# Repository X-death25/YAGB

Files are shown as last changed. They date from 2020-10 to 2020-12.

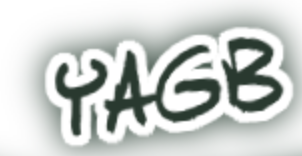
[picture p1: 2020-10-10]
PCB/gfx/yagb.PNG

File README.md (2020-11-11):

# YAGB
Yes Another GameBoy dumper  
STM32 USB Game Boy / Color cartridge Reader/Writer 

YAGB_pcb YAGB_pcb2  

What is it ?
-----

YAGB is an USB cart Reader/Flasher for Nintendo Gameboy / Gameboy Color. 
You can backup/restore your game ROMs/save games to your PC and write ROMs to third pary Flash cart.
it's a full usp high speed programmer and 100% open source Hardware & Sofyware.
You can backup / restore your cartridge and save for use it in Flashcart or Emu.
Feel free to do what you want with that 

Product Feature :
-----

    Read Nintendo Gameboy / Color cartridge up to 16 Meg
    Support Bankswitch for ROM & Saves
    Manage / Backup / Restore your own saves
    Reflash Third-Party Cartridges
    Universal Serial Bus USB2 Power & Use
    Multi OS compatibility Windows/Linux/Mac
    Open Source Hardware & Software
    
How to use it :
-----

You just need a micro USB to USB cable. Plug it and start the software.
Operating System Compatibility

Microsoft Windows XP / 7 / 8 / 10 / Linux / MAC OS

What make it special ?
-----

I wanted to use only classic component for the hardware easy findable on the net. Board microprocessor uses its own native USB transfer protocol so it's fast even for the large games, no need for any extra USB transceiver. I have made the choice to have fully open source hardware & software parts. All of the part list is easy to solder, even for a complete beginner, so everyone can make it. You can also buy a ready to use dumper.

Where i can buy it ?
-----

https://www.tindie.com/products/xdeath/yagb-yes-another-gameboy-dumper/

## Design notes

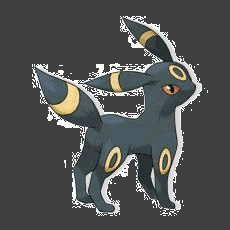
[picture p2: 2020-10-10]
PCB/gfx/noctali.png

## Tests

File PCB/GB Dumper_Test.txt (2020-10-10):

(kicad_pcb (version 20171130) (host pcbnew 5.0.2-bee76a0~70~ubuntu18.10.1)

  (general
    (thickness 1.2)
    (drawings 50)
    (tracks 478)
    (zones 0)
    (modules 24)
    (nets 40)
  )

  (page A4)
  (title_block
    (title GB-BRK-SLOT-A)
    (rev v1.0)
    (company https://gekkio.fi)
  )

  (layers
    (0 F.Cu signal)
    (31 B.Cu signal)
    (32 B.Adhes user)
    (33 F.Adhes user)
    (34 B.Paste user)
    (35 F.Paste user)
    (36 B.SilkS user)
    (37 F.SilkS user)
    (38 B.Mask user)
    (39 F.Mask user)
    (40 Dwgs.User user)
    (41 Cmts.User user)
    (42 Eco1.User user)
    (43 Eco2.User user)
    (44 Edge.Cuts user)
    (45 Margin user)
    (46 B.CrtYd user)
    (47 F.CrtYd user)
    (48 B.Fab user)
    (49 F.Fab user)
  )

  (setup
    (last_trace_width 0.32)
    (user_trace_width 0.8)
    (trace_clearance 0.2)
    (zone_clearance 0.254)
    (zone_45_only yes)
    (trace_min 0.2)
    (segment_width 0.2)
    (edge_width 0.15)
    (via_size 0.6)
    (via_drill 0.4)
    (via_min_size 0.4)
    (via_min_drill 0.3)
    (user_via 1 0.8)
    (uvia_size 0.3)
    (uvia_drill 0.1)
    (uvias_allowed no)
    (uvia_min_size 0.2)
    (uvia_min_drill 0.1)
    (pcb_text_width 0.3)
    (pcb_text_size 1.5 1.5)
    (mod_edge_width 0.15)
    (mod_text_size 1 1)
    (mod_text_width 0.15)
    (pad_size 1.524 1.524)
    (pad_drill 0.762)
    (pad_to_mask_clearance 0)
    (solder_mask_min_width 0.2)
    (aux_axis_origin 0 0)
    (visible_elements FFFFFF7F)
    (pcbplotparams
      (layerselection 0x010fc_ffffffff)
      (usegerberextensions false)
      (usegerberattributes false)
      (usegerberadvancedattributes false)
      (creategerberjobfile true)
      (excludeedgelayer false)
      (linewidth 0.100000)
      (plotframeref false)
      (viasonmask false)
      (mode 1)
      (useauxorigin false)
      (hpglpennumber 1)
      (hpglpenspeed 20)
      (hpglpendiameter 15.000000)
      (psnegative false)
      (psa4output false)
      (plotreference true)
      (plotvalue true)
      (plotinvisibletext false)
      (padsonsilk false)
      (subtractmaskfromsilk false)
      (outputformat 1)
      (mirror false)
      (drillshape 0)
      (scaleselection 1)
      (outputdirectory "gerber/"))
  )

  (net 0 "")
  (net 1 "Net-(D1-Pad2)")
  (net 2 +5V)
  (net 3 GND)
  (net 4 /A0)
  (net 5 /PHI)
  (net 6 /A1)
  (net 7 /~WR)
  (net 8 /A2)
  (net 9 /~RD)
  (net 10 /A3)
  (net 11 /~CS)
  (net 12 /A4)
  (net 13 /D0)
  (net 14 /A5)
  (net 15 /D1)
  (net 16 /A6)
  (net 17 /D2)
  (net 18 /A7)
  (net 19 /D3)
  (net 20 /A8)
  (net 21 /D4)
  (net 22 /A9)
  (net 23 /D5)
  (net 24 /A10)
  (net 25 /D6)
  (net 26 /A11)
  (net 27 /D7)
  (net 28 /A12)
  (net 29 /~RES)
  (net 30 /A13)
  (net 31 /VIN)
  (net 32 /A14)
  (net 33 /A15)
  (net 34 "Net-(D2-Pad2)")
  (net 35 "Net-(D3-Pad2)")
  (net 36 "Net-(D4-Pad2)")
  (net 37 "Net-(D5-Pad2)")
  (net 38 "Net-(D6-Pad2)")
  (net 39 "Net-(J3-Pad1)")

  (net_class Default "This is the default net class."
    (clearance 0.2)
    (trace_width 0.32)
    (via_dia 0.6)
    (via_drill 0.4)
    (uvia_dia 0.3)
    (uvia_drill 0.1)
    (add_net /A0)
    (add_net /A1)
    (add_net /A10)
    (add_net /A11)
    (add_net /A12)
    (add_net /A13)
    (add_net /A14)
    (add_net /A15)
    (add_net /A2)
    (add_net /A3)
    (add_net /A4)
    (add_net /A5)
    (add_net /A6)
    (add_net /A7)
    (add_net /A8)
    (add_net /A9)
    (add_net /D0)
    (add_net /D1)
    (add_net /D2)
    (add_net /D3)
    (add_net /D4)
    (add_net /D5)
    (add_net /D6)
    (add_net /D7)
    (add_net /PHI)
    (add_net /VIN)
    (add_net /~CS)
    (add_net /~RD)
    (add_net /~RES)
    (add_net /~WR)
    (add_net "Net-(D1-Pad2)")
    (add_net "Net-(D2-Pad2)")
    (add_net "Net-(D3-Pad2)")
    (add_net "Net-(D4-Pad2)")
    (add_net "Net-(D5-Pad2)")
    (add_net "Net-(D6-Pad2)")
    (add_net "Net-(J3-Pad1)")
  )

  (net_class Power ""
    (clearance 0.3)
    (trace_width 0.8)
    (via_dia 1)
    (via_drill 0.8)
    (uvia_dia 0.3)
    (uvia_drill 0.1)
    (add_net +5V)
    (add_net GND)
  )

  (module Connector_PinHeader_2.54mm:PinHeader_1x02_P2.54mm_Vertical (layer F.Cu) (tedit 59FED5CC) (tstamp 5C2EC759)
    (at 58.3 103.3 180)
    (descr "Through hole straight pin header, 1x02, 2.54mm pitch, single row")
    (tags "Through hole pin header THT 1x02 2.54mm single row")
    (path /5C2E6B56)
    (fp_text reference JP1 (at 0 -2.33 180) (layer F.SilkS)
      (effects (font (size 1 1) (thickness 0.15)))
    )
    (fp_text value Jumper_NC_Small (at 0 4.87 180) (layer F.Fab)
      (effects (font (size 1 1) (thickness 0.15)))
    )
    (fp_text user %R (at 0 1.27 270) (layer F.Fab)
      (effects (font (size 1 1) (thickness 0.15)))
    )
    (fp_line (start 1.8 -1.8) (end -1.8 -1.8) (layer F.CrtYd) (width 0.05))
    (fp_line (start 1.8 4.35) (end 1.8 -1.8) (layer F.CrtYd) (width 0.05))
    (fp_line (start -1.8 4.35) (end 1.8 4.35) (layer F.CrtYd) (width 0.05))
    (fp_line (start -1.8 -1.8) (end -1.8 4.35) (layer F.CrtYd) (width 0.05))
    (fp_line (start -1.33 -1.33) (end 0 -1.33) (layer F.SilkS) (width 0.12))
    (fp_line (start -1.33 0) (end -1.33 -1.33) (layer F.SilkS) (width 0.12))
    (fp_line (start -1.33 1.27) (end 1.33 1.27) (layer F.SilkS) (width 0.12))
    (fp_line (start 1.33 1.27) (end 1.33 3.87) (layer F.SilkS) (width 0.12))
    (fp_line (start -1.33 1.27) (end -1.33 3.87) (layer F.SilkS) (width 0.12))
    (fp_line (start -1.33 3.87) (end 1.33 3.87) (layer F.SilkS) (width 0.12))
    (fp_line (start -1.27 -0.635) (end -0.635 -1.27) (layer F.Fab) (width 0.1))
    (fp_line (start -1.27 3.81) (end -1.27 -0.635) (layer F.Fab) (width 0.1))
    (fp_line (start 1.27 3.81) (end -1.27 3.81) (layer F.Fab) (width 0.1))
    (fp_line (start 1.27 -1.27) (end 1.27 3.81) (layer F.Fab) (width 0.1))
    (fp_line (start -0.635 -1.27) (end 1.27 -1.27) (layer F.Fab) (width 0.1))
    (pad 2 thru_hole oval (at 0 2.54 180) (size 1.7 1.7) (drill 1) (layers *.Cu *.Mask)
      (net 39 "Net-(J3-Pad1)"))
    (pad 1 thru_hole rect (at 0 0 180) (size 1.7 1.7) (drill 1) (layers *.Cu *.Mask)
      (net 2 +5V))
    (model ${KISYS3DMOD}/Connector_PinHeader_2.54mm.3dshapes/PinHeader_1x02_P2.54mm_Vertical.wrl
      (at (xyz 0 0 0))
      (scale (xyz 1 1 1))
      (rotate (xyz 0 0 0))
    )
  )

  (module Resistor_SMD:R_1206_3216Metric_Pad1.42x1.75mm_HandSolder (layer F.Cu) (tedit 5B301BBD) (tstamp 5BF060DE)
    (at 64.25 101.69 270)
    (descr "Resistor SMD 1206 (3216 Metric), square (rectangular) end terminal, IPC_7351 nominal with elongated pad for handsoldering. (Body size source: http://www.tortai-tech.com/upload/download/2011102023233369053.pdf), generated with kicad-footprint-generator")
    (tags "resistor handsolder")
    (path /5BF0DED2)
    (attr smd)
    (fp_text reference R7 (at -0.01 2.24) (layer F.SilkS)
      (effects (font (size 1 1) (thickness 0.15)))
    )
    (fp_text value 0R (at 1.34 2.3) (layer F.Fab)
      (effects (font (size 1 1) (thickness 0.15)))
    )
    (fp_text user %R (at 0 0 270) (layer F.Fab)
      (effects (font (size 0.8 0.8) (thickness 0.12)))
    )
    (fp_line (start 2.45 1.12) (end -2.45 1.12) (layer F.CrtYd) (width 0.05))
    (fp_line (start 2.45 -1.12) (end 2.45 1.12) (layer F.CrtYd) (width 0.05))
    (fp_line (start -2.45 -1.12) (end 2.45 -1.12) (layer F.CrtYd) (width 0.05))
    (fp_line (start -2.45 1.12) (end -2.45 -1.12) (layer F.CrtYd) (width 0.05))
    (fp_line (start -0.602064 0.91) (end 0.602064 0.91) (layer F.SilkS) (width 0.12))
    (fp_line (start -0.602064 -0.91) (end 0.602064 -0.91) (layer F.SilkS) (width 0.12))
    (fp_line (start 1.6 0.8) (end -1.6 0.8) (layer F.Fab) (width 0.1))
    (fp_line (start 1.6 -0.8) (end 1.6 0.8) (layer F.Fab) (width 0.1))
    (fp_line (start -1.6 -0.8) (end 1.6 -0.8) (layer F.Fab) (width 0.1))
    (fp_line (start -1.6 0.8) (end -1.6 -0.8) (layer F.Fab) (width 0.1))
    (pad 2 smd roundrect (at 1.4875 0 270) (size 1.425 1.75) (layers F.Cu F.Paste F.Mask) (roundrect_rratio 0.175439)
      (net 2 +5V))
    (pad 1 smd roundrect (at -1.4875 0 270) (size 1.425 1.75) (layers F.Cu F.Paste F.Mask) (roundrect_rratio 0.175439)
      (net 39 "Net-(J3-Pad1)"))
    (model ${KISYS3DMOD}/Resistor_SMD.3dshapes/R_1206_3216Metric.wrl
      (at (xyz 0 0 0))
      (scale (xyz 1 1 1))
      (rotate (xyz 0 0 0))
    )
  )

  (module LED_SMD:LED_0603_1608Metric (layer F.Cu) (tedit 5B301BBE) (tstamp 5A985B06)
    (at 65 148.4)
    (descr "LED SMD 0603 (1608 Metric), square (rectangular) end terminal, IPC_7351 nominal, (Body size source: http://www.tortai-tech.com/upload/download/2011102023233369053.pdf), generated with kicad-footprint-generator")
    (tags diode)
    (path /5A985CB3)
    (attr smd)
    (fp_text reference D1 (at -15.5 0.3) (layer F.SilkS)
      (effects (font (size 1 1) (thickness 0.15)))
    )
    (fp_text value LED (at 0 1.65) (layer F.Fab)
      (effects (font (size 1 1) (thickness 0.15)))
    )
    (fp_text user %R (at 0 0) (layer F.Fab)
      (effects (font (size 0.4 0.4) (thickness 0.06)))
    )
    (fp_line (start 1.48 0.73) (end -1.48 0.73) (layer F.CrtYd) (width 0.05))
    (fp_line (start 1.48 -0.73) (end 1.48 0.73) (layer F.CrtYd) (width 0.05))
    (fp_line (start -1.48 -0.73) (end 1.48 -0.73) (layer F.CrtYd) (width 0.05))
    (fp_line (start -1.48 0.73) (end -1.48 -0.73) (layer F.CrtYd) (width 0.05))
    (fp_line (start -1.485 0.735) (end 0.8 0.735) (layer F.SilkS) (width 0.12))
    (fp_line (start -1.485 -0.735) (end -1.485 0.735) (layer F.SilkS) (width 0.12))
    (fp_line (start 0.8 -0.735) (end -1.485 -0.735) (layer F.SilkS) (width 0.12))
    (fp_line (start 0.8 0.4) (end 0.8 -0.4) (layer F.Fab) (width 0.1))
    (fp_line (start -0.8 0.4) (end 0.8 0.4) (layer F.Fab) (width 0.1))
    (fp_line (start -0.8 -0.1) (end -0.8 0.4) (layer F.Fab) (width 0.1))
    (fp_line (start -0.5 -0.4) (end -0.8 -0.1) (layer F.Fab) (width 0.1))
    (fp_line (start 0.8 -0.4) (end -0.5 -0.4) (layer F.Fab) (width 0.1))
    (pad 2 smd roundrect (at 0.7875 0) (size 0.875 0.95) (layers F.Cu F.Paste F.Mask) (roundrect_rratio 0.25)
      (net 1 "Net-(D1-Pad2)"))
    (pad 1 smd roundrect (at -0.7875 0) (size 0.875 0.95) (layers F.Cu F.Paste F.Mask) (roundrect_rratio 0.25)
      (net 3 GND))
    (model ${KISYS3DMOD}/LED_SMD.3dshapes/LED_0603_1608Metric.wrl
      (at (xyz 0 0 0))
      (scale (xyz 1 1 1))
      (rotate (xyz 0 0 0))
    )
  )

  (module Connector_PinHeader_2.54mm:PinHeader_2x16_P2.54mm_Vertical locked (layer F.Cu) (tedit 59FED5CC) (tstamp 5A985B2A)
    (at 68.45 120 90)
    (descr "Through hole straight pin header, 2x16, 2.54mm pitch, double rows")
    (tags "Through hole pin header THT 2x16 2.54mm double row")
    (path /5A985BF6)
    (fp_text reference J2 (at 1.27 -2.33 90) (layer F.SilkS)
      (effects (font (size 1 1) (thickness 0.15)))
    )
    (fp_text value Conn_02x16_Odd_Even (at 1.27 40.43 90) (layer F.Fab)
      (effects (font (size 1 1) (thickness 0.15)))
    )
    (fp_text user %R (at 1.27 19.05 180) (layer F.Fab)
      (effects (font (size 1 1) (thickness 0.15)))
    )
    (fp_line (start 4.35 -1.8) (end -1.8 -1.8) (layer F.CrtYd) (width 0.05))
    (fp_line (start 4.35 39.9) (end 4.35 -1.8) (layer F.CrtYd) (width 0.05))
    (fp_line (start -1.8 39.9) (end 4.35 39.9) (layer F.CrtYd) (width 0.05))
    (fp_line (start -1.8 -1.8) (end -1.8 39.9) (layer F.CrtYd) (width 0.05))
    (fp_line (start -1.33 -1.33) (end 0 -1.33) (layer F.SilkS) (width 0.12))
    (fp_line (start -1.33 0) (end -1.33 -1.33) (layer F.SilkS) (width 0.12))
    (fp_line (start 1.27 -1.33) (end 3.87 -1.33) (layer F.SilkS) (width 0.12))
    (fp_line (start 1.27 1.27) (end 1.27 -1.33) (layer F.SilkS) (width 0.12))
    (fp_line (start -1.33 1.27) (end 1.27 1.27) (layer F.SilkS) (width 0.12))
    (fp_line (start 3.87 -1.33) (end 3.87 39.43) (layer F.SilkS) (width 0.12))
    (fp_line (start -1.33 1.27) (end -1.33 39.43) (layer F.SilkS) (width 0.12))
    (fp_line (start -1.33 39.43) (end 3.87 39.43) (layer F.SilkS) (width 0.12))
    (fp_line (start -1.27 0) (end 0 -1.27) (layer F.Fab) (width 0.1))
    (fp_line (start -1.27 39.37) (end -1.27 0) (layer F.Fab) (width 0.1))
    (fp_line (start 3.81 39.37) (end -1.27 39.37) (layer F.Fab) (width 0.1))
    (fp_line (start 3.81 -1.27) (end 3.81 39.37) (layer F.Fab) (width 0.1))
    (fp_line (start 0 -1.27) (end 3.81 -1.27) (layer F.Fab) (width 0.1))
    (pad 32 thru_hole oval (at 2.54 38.1 90) (size 1.7 1.7) (drill 1) (layers *.Cu *.Mask)
      (net 3 GND))
    (pad 31 thru_hole oval (at 0 38.1 90) (size 1.7 1.7) (drill 1) (layers *.Cu *.Mask)
      (net 33 /A15))
    (pad 30 thru_hole oval (at 2.54 35.56 90) (size 1.7 1.7) (drill 1) (layers *.Cu *.Mask)
      (net 31 /VIN))
    (pad 29 thru_hole oval (at 0 35.56 90) (size 1.7 1.7) (drill 1) (layers *.Cu *.Mask)
      (net 32 /A14))
    (pad 28 thru_hole oval (at 2.54 33.02 90) (size 1.7 1.7) (drill 1) (layers *.Cu *.Mask)
      (net 29 /~RES))
    (pad 27 thru_hole oval (at 0 33.02 90) (size 1.7 1.7) (drill 1) (layers *.Cu *.Mask)
      (net 30 /A13))
    (pad 26 thru_hole oval (at 2.54 30.48 90) (size 1.7 1.7) (drill 1) (layers *.Cu *.Mask)
      (net 27 /D7))
    (pad 25 thru_hole oval (at 0 30.48 90) (size 1.7 1.7) (drill 1) (layers *.Cu *.Mask)
      (net 28 /A12))
    (pad 24 thru_hole oval (at 2.54 27.94 90) (size 1.7 1.7) (drill 1) (layers *.Cu *.Mask)
      (net 25 /D6))
    (pad 23 thru_hole oval (at 0 27.94 90) (size 1.7 1.7) (drill 1) (layers *.Cu *.Mask)
      (net 26 /A11))
    (pad 22 thru_hole oval (at 2.54 25.4 90) (size 1.7 1.7) (drill 1) (layers *.Cu *.Mask)
      (net 23 /D5))
    (pad 21 thru_hole oval (at 0 25.4 90) (size 1.7 1.7) (drill 1) (layers *.Cu *.Mask)
      (net 24 /A10))
    (pad 20 thru_hole oval (at 2.54 22.86 90) (size 1.7 1.7) (drill 1) (layers *.Cu *.Mask)
      (net 21 /D4))
    (pad 19 thru_hole oval (at 0 22.86 90) (size 1.7 1.7) (drill 1) (layers *.Cu *.Mask)
      (net 22 /A9))
    (pad 18 thru_hole oval (at 2.54 20.32 90) (size 1.7 1.7) (drill 1) (layers *.Cu *.Mask)
      (net 19 /D3))
    (pad 17 thru_hole oval (at 0 20.32 90) (size 1.7 1.7) (drill 1) (layers *.Cu *.Mask)
      (net 20 /A8))
    (pad 16 thru_hole oval (at 2.54 17.78 90) (size 1.7 1.7) (drill 1) (layers *.Cu *.Mask)
      (net 17 /D2))
    (pad 15 thru_hole oval (at 0 17.78 90) (size 1.7 1.7) (drill 1) (layers *.Cu *.Mask)
      (net 18 /A7))
    (pad 14 thru_hole oval (at 2.54 15.24 90) (size 1.7 1.7) (drill 1) (layers *.Cu *.Mask)
      (net 15 /D1))
    (pad 13 thru_hole oval (at 0 15.24 90) (size 1.7 1.7) (drill 1) (layers *.Cu *.Mask)
      (net 16 /A6))
    (pad 12 thru_hole oval (at 2.54 12.7 90) (size 1.7 1.7) (drill 1) (layers *.Cu *.Mask)
      (net 13 /D0))
    (pad 11 thru_hole oval (at 0 12.7 90) (size 1.7 1.7) (drill 1) (layers *.Cu *.Mask)
      (net 14 /A5))
    (pad 10 thru_hole oval (at 2.54 10.16 90) (size 1.7 1.7) (drill 1) (layers *.Cu *.Mask)
      (net 11 /~CS))
    (pad 9 thru_hole oval (at 0 10.16 90) (size 1.7 1.7) (drill 1) (layers *.Cu *.Mask)
      (net 12 /A4))
    (pad 8 thru_hole oval (at 2.54 7.62 90) (size 1.7 1.7) (drill 1) (layers *.Cu *.Mask)
      (net 9 /~RD))
    (pad 7 thru_hole oval (at 0 7.62 90) (size 1.7 1.7) (drill 1) (layers *.Cu *.Mask)
      (net 10 /A3))
    (pad 6 thru_hole oval (at 2.54 5.08 90) (size 1.7 1.7) (drill 1) (layers *.Cu *.Mask)
      (net 7 /~WR))
    (pad 5 thru_hole oval (at 0 5.08 90) (size 1.7 1.7) (drill 1) (layers *.Cu *.Mask)
      (net 8 /A2))
    (pad 4 thru_hole oval (at 2.54 2.54 90) (size 1.7 1.7) (drill 1) (layers *.Cu *.Mask)
      (net 5 /PHI))
    (pad 3 thru_hole oval (at 0 2.54 90) (size 1.7 1.7) (drill 1) (layers *.Cu *.Mask)
      (net 6 /A1))
    (pad 2 thru_hole oval (at 2.54 0 90) (size 1.7 1.7) (drill 1) (layers *.Cu *.Mask)
      (net 2 +5V))
    (pad 1 thru_hole rect (at 0 0 90) (size 1.7 1.7) (drill 1) (layers *.Cu *.Mask)
      (net 4 /A0))
    (model ${KISYS3DMOD}/Connector_PinHeader_2.54mm.3dshapes/PinHeader_2x16_P2.54mm_Vertical.wrl
      (at (xyz 0 0 0))
      (scale (xyz 1 1 1))
      (rotate (xyz 0 0 0))
    )
  )

  (module Resistor_SMD:R_0603_1608Metric (layer F.Cu) (tedit 5B301BBD) (tstamp 5A985B90)
    (at 65 146.8)
    (descr "Resistor SMD 0603 (1608 Metric), square (rectangular) end terminal, IPC_7351 nominal, (Body size source: http://www.tortai-tech.com/upload/download/2011102023233369053.pdf), generated with kicad-footprint-generator")
    (tags resistor)
    (path /5A985D2A)
    (attr smd)
    (fp_text reference R1 (at -15.5 0.6) (layer F.SilkS)
      (effects (font (size 1 1) (thickness 0.15)))
    )
    (fp_text value 3.3k (at 0 1.65) (layer F.Fab)
      (effects (font (size 1 1) (thickness 0.15)))
    )
    (fp_text user %R (at 0 0) (layer F.Fab)
      (effects (font (size 0.4 0.4) (thickness 0.06)))
    )
    (fp_line (start 1.48 0.73) (end -1.48 0.73) (layer F.CrtYd) (width 0.05))
    (fp_line (start 1.48 -0.73) (end 1.48 0.73) (layer F.CrtYd) (width 0.05))
    (fp_line (start -1.48 -0.73) (end 1.48 -0.73) (layer F.CrtYd) (width 0.05))
    (fp_line (start -1.48 0.73) (end -1.48 -0.73) (layer F.CrtYd) (width 0.05))
    (fp_line (start -0.162779 0.51) (end 0.162779 0.51) (layer F.SilkS) (width 0.12))
    (fp_line (start -0.162779 -0.51) (end 0.162779 -0.51) (layer F.SilkS) (width 0.12))
    (fp_line (start 0.8 0.4) (end -0.8 0.4) (layer F.Fab) (width 0.1))
    (fp_line (start 0.8 -0.4) (end 0.8 0.4) (layer F.Fab) (width 0.1))
    (fp_line (start -0.8 -0.4) (end 0.8 -0.4) (layer F.Fab) (width 0.1))
    (fp_line (start -0.8 0.4) (end -0.8 -0.4) (layer F.Fab) (width 0.1))
    (pad 2 smd roundrect (at 0.7875 0) (size 0.875 0.95) (layers F.Cu F.Paste F.Mask) (roundrect_rratio 0.25)
      (net 1 "Net-(D1-Pad2)"))
    (pad 1 smd roundrect (at -0.7875 0) (size 0.875 0.95) (layers F.Cu F.Paste F.Mask) (roundrect_rratio 0.25)
      (net 2 +5V))
    (model ${KISYS3DMOD}/Resistor_SMD.3dshapes/R_0603_1608Metric.wrl
      (at (xyz 0 0 0))
      (scale (xyz 1 1 1))
      (rotate (xyz 0 0 0))
    )
  )

  (module Capacitor_SMD:C_1206_3216Metric (layer F.Cu) (tedit 5B301BBE) (tstamp 5A986974)
    (at 67 132.6 180)
    (descr "Capacitor SMD 1206 (3216 Metric), square (rectangular) end terminal, IPC_7351 nominal, (Body size source: http://www.tortai-tech.com/upload/download/2011102023233369053.pdf), generated with kicad-footprint-generator")
    (tags capacitor)
    (path /5A985D9A)
    (attr smd)
    (fp_text reference C1 (at 0 1.9 180) (layer F.SilkS)
      (effects (font (size 1 1) (thickness 0.15)))
    )
    (fp_text value 10uF (at 5.3 0 180) (layer F.Fab)
      (effects (font (size 1 1) (thickness 0.15)))
    )
    (fp_text user %R (at 0 0 180) (layer F.Fab)
      (effects (font (size 0.8 0.8) (thickness 0.12)))
    )
    (fp_line (start 2.28 1.12) (end -2.28 1.12) (layer F.CrtYd) (width 0.05))
    (fp_line (start 2.28 -1.12) (end 2.28 1.12) (layer F.CrtYd) (width 0.05))
    (fp_line (start -2.28 -1.12) (end 2.28 -1.12) (layer F.CrtYd) (width 0.05))
    (fp_line (start -2.28 1.12) (end -2.28 -1.12) (layer F.CrtYd) (width 0.05))
    (fp_line (start -0.602064 0.91) (end 0.602064 0.91) (layer F.SilkS) (width 0.12))
    (fp_line (start -0.602064 -0.91) (end 0.602064 -0.91) (layer F.SilkS) (width 0.12))
    (fp_line (start 1.6 0.8) (end -1.6 0.8) (layer F.Fab) (width 0.1))
    (fp_line (start 1.6 -0.8) (end 1.6 0.8) (layer F.Fab) (width 0.1))
    (fp_line (start -1.6 -0.8) (end 1.6 -0.8) (layer F.Fab) (width 0.1))
    (fp_line (start -1.6 0.8) (end -1.6 -0.8) (layer F.Fab) (width 0.1))
    (pad 2 smd roundrect (at 1.4 0 180) (size 1.25 1.75) (layers F.Cu F.Paste F.Mask) (roundrect_rratio 0.2)
      (net 3 GND))
    (pad 1 smd roundrect (at -1.4 0 180) (size 1.25 1.75) (layers F.Cu F.Paste F.Mask) (roundrect_rratio 0.2)
      (net 2 +5V))
    (model ${KISYS3DMOD}/Capacitor_SMD.3dshapes/C_1206_3216Metric.wrl
      (at (xyz 0 0 0))
      (scale (xyz 1 1 1))
      (rotate (xyz 0 0 0))
    )
  )

  (module Capacitor_SMD:C_0603_1608Metric (layer F.Cu) (tedit 5B301BBE) (tstamp 5A986979)
    (at 67.6 129.1 180)
    (descr "Capacitor SMD 0603 (1608 Metric), square (rectangular) end terminal, IPC_7351 nominal, (Body size source: http://www.tortai-tech.com/upload/download/2011102023233369053.pdf), generated with kicad-footprint-generator")
    (tags capacitor)
    (path /5A985DFF)
    (attr smd)
    (fp_text reference C2 (at 0.7 1.6 180) (layer F.SilkS)
      (effects (font (size 1 1) (thickness 0.15)))
    )
    (fp_text value 0.1uF (at 5.1 0 180) (layer F.Fab)
      (effects (font (size 1 1) (thickness 0.15)))
    )
    (fp_text user %R (at 0 0 180) (layer F.Fab)
      (effects (font (size 0.4 0.4) (thickness 0.06)))
    )
    (fp_line (start 1.48 0.73) (end -1.48 0.73) (layer F.CrtYd) (width 0.05))
    (fp_line (start 1.48 -0.73) (end 1.48 0.73) (layer F.CrtYd) (width 0.05))
    (fp_line (start -1.48 -0.73) (end 1.48 -0.73) (layer F.CrtYd) (width 0.05))
    (fp_line (start -1.48 0.73) (end -1.48 -0.73) (layer F.CrtYd) (width 0.05))
    (fp_line (start -0.162779 0.51) (end 0.162779 0.51) (layer F.SilkS) (width 0.12))
    (fp_line (start -0.162779 -0.51) (end 0.162779 -0.51) (layer F.SilkS) (width 0.12))
    (fp_line (start 0.8 0.4) (end -0.8 0.4) (layer F.Fab) (width 0.1))
    (fp_line (start 0.8 -0.4) (end 0.8 0.4) (layer F.Fab) (width 0.1))
    (fp_line (start -0.8 -0.4) (end 0.8 -0.4) (layer F.Fab) (width 0.1))
    (fp_line (start -0.8 0.4) (end -0.8 -0.4) (layer F.Fab) (width 0.1))
    (pad 2 smd roundrect (at 0.7875 0 180) (size 0.875 0.95) (layers F.Cu F.Paste F.Mask) (roundrect_rratio 0.25)
      (net 3 GND))
    (pad 1 smd roundrect (at -0.7875 0 180) (size 0.875 0.95) (layers F.Cu F.Paste F.Mask) (roundrect_rratio 0.25)
      (net 2 +5V))
    (model ${KISYS3DMOD}/Capacitor_SMD.3dshapes/C_0603_1608Metric.wrl
      (at (xyz 0 0 0))
      (scale (xyz 1 1 1))
      (rotate (xyz 0 0 0))
    )
  )
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

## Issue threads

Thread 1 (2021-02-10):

Component list

dennisjanssen, 2021-02-10:
Hi!

First of all, great project! I've been looking for an easy DIY method of making one of these. From what I can tell it's still WIP, but your goal is to be able to flash a new ROM to an unlocked flash cart?

I've been looking at the PCB files, from what I can tell I'll need these components:

- 2x 74LS273 (https://nl.aliexpress.com/item/1005001792133844.html?spm=a2g0o.cart.0.0.50d13c00pjkaV7&mp=1)
- 1x game cartridge slot (https://nl.aliexpress.com/item/4001322498055.html?spm=a2g0o.cart.0.0.50d13c00pjkaV7&mp=1)
- 2x MKS02 (https://nl.aliexpress.com/item/4000403102318.html)
- 1x STM32 board (https://nl.aliexpress.com/item/1005001621944261.html)

And then just order the PCB from PCBway, JLCPCB, ...

If I got all of that right I'll start ordering and build one.

X-death25, 2021-02-10:
Hi,
Yes sorry i missed the part list  👍
so :

74LS273N : https://fr.aliexpress.com/item/32879353216.html
GB/GBC cartridge slot : https://fr.aliexpress.com/item/33007365661.html
100nF condensator ( can works without but it's better ) :  https://fr.aliexpress.com/item/1005002060914434.html
STM32 ( i recommand the Rebotdyn design for better USB support but blue pill can works too :
https://fr.aliexpress.com/item/3301602535

And then yes just drag the gerber files on any PCB builder shop.
Wish you great build !

dennisjanssen, 2021-02-10:
This is great, thanks! Any idea on cartridge compatibility? I'm guessing it takes some custom work based on the cartridge chipset, since most flasher list these. Any recommendations?

dennisjanssen, 2021-04-08:
Just in case any other total noob like myself reads this afterwards, a USB TTL adapter apparently is also pretty useful when you order an STM32 that doesn't come preflashed.

I ordered this one: https://nl.aliexpress.com/item/4000308135007.html?spm=a2g0s.9042311.0.0.7b984c4dJZShqL

X-death25, 2021-04-10:
Hi,
you can also use ST-link clone and official STM32 ST-link utility

https://fr.aliexpress.com/item/1827010981.html?
After that i use this bootloader for dev
https://github.com/rogerclarkmelbourne/STM32duino-bootloader
and this for release ( user don't need to install driver for the second)
https://github.com/Serasidis/STM32_HID_Bootloader

dennisjanssen, 2021-04-15:
You are probably right, not having much luck with the USB-TTL adapter in any method available. Ordered an ST-LINK programmer on AliExpress now, so I'll be waiting for a while now.

I do have some cartridges around, as well as a bunch of Chinese reproductions, so very curious about compatibility. I noticed you added flash capabilities too, would be very interesting to flash ROMs to those Chinese cartridges. I'll keep you posted on progress!

dennisjanssen, 2021-04-18:
I managed to get it working with a UART adapter after all, got the HID bootloader on there and managed to flash your firmware through the script, so I'm fully done hardware wise!

Started testing with some cartridges, managed to dump one (type C9 according to the dumper), but you're right, Pokemon Red (MBC5) is giving me trouble. Also tried to dump a bootleg cartridge, which gave me a .gb file with the correct size, but it's not functional. Also tried to flash one of those with another ROM, no luck. What did work on that bootleg cartridge was erasing flash, it now says it's empty and will only return an empty .gb file when dumping. Weirdly enough the cartridge still works fine in a GameBoy, the ROM is still there.

dennisjanssen, 2021-04-19:
Sorry to spam these comments, but I've been combing through code and looking up other examples to add compatibility with more types of cartridges, when I came across this: https://github.com/lesserkuma/FlashGBX

They seems set up in a way that allows them to add more hardware devices to their flashing/dumping software and already offer a very broad range of different cartridges. Maybe it's a good idea to collaborate? Connect their software with your firmware to offer a very complete solution?

X-death25, 2021-04-20:
1)Good to read you have sucessfully flashed it , now with bootloader inside , update will be easier.
Did you have troubles with a lot of cartrige ? i have my all collections sucessfully.
Some games with MBC5 dumps correctly for exemple Oracle of Seasons.
Lots of chinese cartridge bootleg use crappy flash with no level shifter or some uncommun mapper clone.
Can you report me game that's don't works correctly ?
I don't have Rewritable GB cartridge in my hand so can't do real hardware test for reflash code.

2)Github links you show it's just a graphical interface for GBxCart and not include mapper support ( these code are in  GBxCart  firmware and maybe not open source).
GBxCart use Atmel 5V processor for better compatibility but harder to solder and costs a lot more.
All of these design is open source so feel free to do what you want with it.

dennisjanssen, 2021-04-20:
So far Pokemon Red gave me trouble, Power Rangers The Movie worked fine. But I'll test a bit more to rule out I have hardware trouble or something.

On the software side, bear with me. And quick disclaimer, I barely consider myself a programmer, so I might have all of this wrong. I took a look at GBxCart since they seem to have the broadest support for all kinds of cartridges. Turns out their firmware isn't exactly closed source, I found it here: https://github.com/insidegadgets/GBxCart-RW/blob/06b1ac4196e76209cee02668608f618dbebd87ed/MCU_Files/GBxCart_RW_v1.3_R22/main.c

I was expecting to see mappings for different kinds of cartridges as well, in that file. I haven't found much in there, but maybe I'm looking in the wrong places. As far as I can tell they handle this a bit more backwards than YAGB, where the software part handles the logic and mapping and the firmware just does the reading and writing parts. But you're way better placed to estimate that I suppose.

Anyway, next I started looking into how they communicate between software and firmware, to figure out how that works. FlashGBX seemed like a good place to start since they had to figure out the same thing. As far as I can tell the makers of FlashGBX didn't intend to only work with GBxCart, they even separated the hardware integration in a separate file (https://github.com/lesserkuma/FlashGBX/blob/master/FlashGBX/hw_GBxCartRW.py) that is loaded into an array of devices (https://github.com/lesserkuma/FlashGBX/blob/master/FlashGBX/FlashGBX_GUI.py#L11). That hardware file also seems to hand off certain functions to the firmware (like GBA_FLASH_WRITE_BYTE), which are named the same in the GBxCart fimware. In their commits I found indications that they added support for different kinds of cartridges, which struck me as weird because I also expected that part to be handled by the GBxCart firmware. Turns out they have a massive pile of config files for different types of cartridges (https://github.com/lesserkuma/FlashGBX/tree/master/FlashGBX/config), I'm guessing that's the mapping you mentioned?

Again, I might look at this all wrong (sorry if that's the case), but I think both FlashGBX and the GBxCart firmware have a lot of parts that might be useful for you to add more compatibility (or even troubleshoot the MBC5 cartridges). But it might even be interesting to update the firmware and work on a hardware file with the FlashGBX guys in order to piggyback on a lot of work they already did?

X-death25, 2021-05-09:
Hi,
i have made a special exe for MBC5 issues.
Could you test these file with your Pokemon Red ?
https://github.com/X-death25/YAGB/blob/main/Software/GB_Dumper_mbc5.exe

Greetings

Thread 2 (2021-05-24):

Write Save files

adri6412, 2021-05-24:
I have compiled your software to work on a rasperry pi but when i use the menu to write a dumped save file back to the cartdridge it hangs after i input the name in the save file dialog.

In my windows pc is working fine. Only linux is giving me problems

Is maybe the issue derived to something of the arm platform or is it a bug on linux?

adri6412, 2021-05-24:
I have not mentioned that all the other options do work (like dumping the rom and the save file) just the erase sram and the write sram functions are broken

Closed 2022-05-17.

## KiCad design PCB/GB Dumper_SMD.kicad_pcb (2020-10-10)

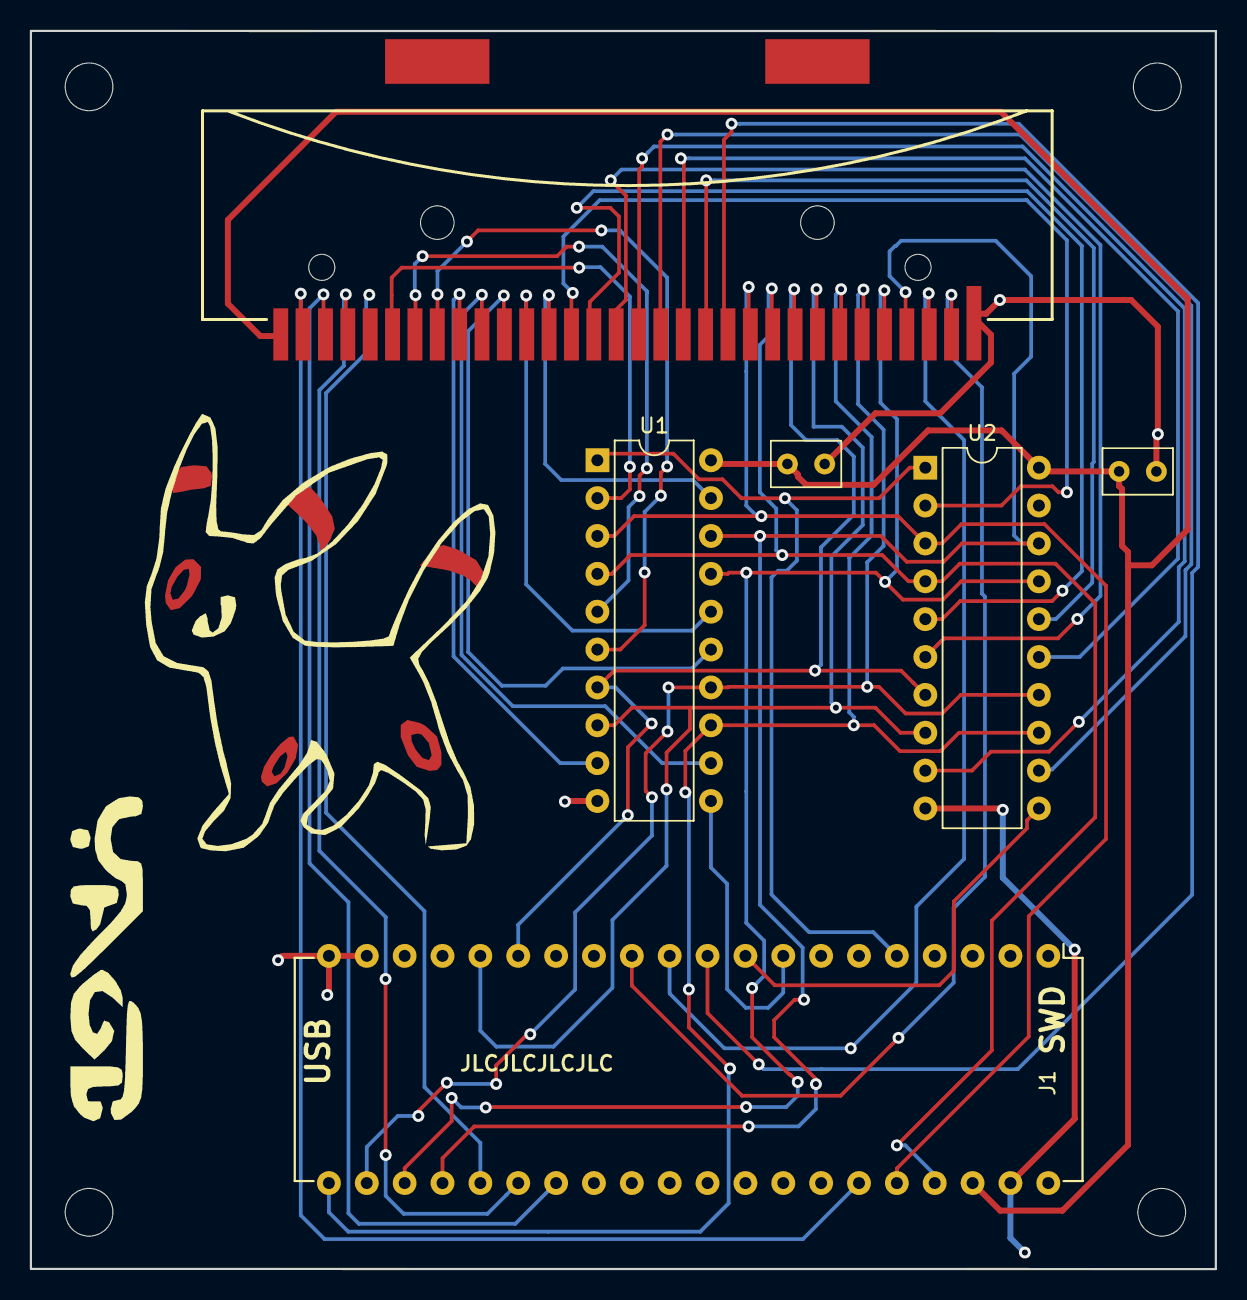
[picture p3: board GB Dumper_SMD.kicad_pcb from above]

Board: 2 copper layers, 79.5 x 83.1 mm, 4 parts (0 on the bottom side), 34 nets.

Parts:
J1: Conn_02x20_Counter_Clockwise; DIP-40_W15.24mm
J2: Conn_01x32_Male; GB_CART_4holes
U1, U2: 74LS273; DIP-20_W7.62mm

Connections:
A0: J2.6, U1.2
A1: J2.7, U1.5
A2: J2.8, U1.6
A3: J2.9, U1.9
A4: J2.10, U1.12
A5: J2.11, U1.15
A6: J2.12, U1.16
A7: J2.13, U1.19
A8: J2.14, U2.2
A9: J2.15, U2.5
A10: J2.16, U2.6
A11: J2.17, U2.9
A12: J2.18, U2.12
A13: J2.19, U2.15
A14: J2.20, U2.16
A15: J1.10, J2.21
Audio_IN: J1.12, J2.31
CPU_Clk: J1.37, J2.2
Clear: J1.5, U1.1, U2.1
Clk1: J1.8, U1.11
Clk2: J1.9, U2.11
D0: J1.36, J2.22, U1.3, U2.3
D1: J1.37, J2.23, U1.4, U2.4
D2: J1.15, J2.24, U1.7, U2.7
D3: J1.16, J2.25, U1.8, U2.8
D4: J1.21, J2.26, U1.13, U2.13
D5: J1.22, J2.27, U1.14, U2.14
D6: J1.23, J2.28, U1.17, U2.17
D7: J1.24, J2.29, U1.18, U2.18
GND: J1.19, J1.20, J1.39, J2.32, U1.10, U2.10
VCC5: J1.38, J2.1, U1.20, U2.20
~RD: J1.26, J2.4
~RST: J1.11, J2.30
~WE: J1.27, J2.3

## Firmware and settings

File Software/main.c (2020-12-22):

/*
 * \file main.c
 * \brief Libusb software for communicate with STM32
 * \author X-death for Ultimate-Consoles forum (http://www.ultimate-consoles.fr)
 * \date 2018/06
 *
 * just a simple sample for testing libusb and new code of Sega Dumper
 *
 * --------------------------------------------
 */

#include <stdio.h>
#include <stdlib.h>
#include <stdarg.h>
#include <string.h>
#include <ctype.h>
#include <time.h>
#include <math.h>

#include <libusb.h>
#include <assert.h>

// Specific Win32 lib ( only used for debug )

//#include <conio.h>

// USB Special Command

#define WAKEUP  0x10  // WakeUP for first STM32 Communication
#define READ_GB 0x11
#define READ_GB_SAVE 0x12
#define ERASE_GB_SAVE 0x17
#define WRITE_GB_SAVE 0x13
#define WRITE_GB_FLASH 	0x14
#define ERASE_GB_FLASH 0x15
#define ERASE_SECTOR 0x16
#define INFOS_ID 0x18
#define DEBUG_MODE 0x19

// Version 

#define MAX_VERSION 	1
#define MIN_VERSION 	2


// Sega Dumper Specific Function

void pause(char const *message)
{
    int c;
 
    printf("%s", message);
    fflush(stdout);
 
    while ((c = getchar()) != '\n' && c != EOF)
    {
    }
}


int main()
{

  // LibUSB Specific Var
    
  int res                      = 0;        /* return codes from libusb functions */
  libusb_device_handle* handle = 0;        /* handle for USB device */
  int kernelDriverDetached     = 0;        /* Set to 1 if kernel driver detached */
  int numBytes                 = 0;        /* Actual bytes transferred. */
  unsigned char usb_buffer_in[64] = {0};   /* 64 byte transfer buffer IN */
  unsigned char usb_buffer_out[64] = {0};  /* 64 byte transfer buffer OUT */
  unsigned long len            = 0;        /* Number of bytes transferred. */

   // Dumper Specific Var

    unsigned long i=0;
	unsigned long j=0;
    unsigned long k=0;
	int choixMenu=0;
	unsigned long address=0;
	unsigned char *BufferROM;
	unsigned char *BufferTemp;
	unsigned char *BufferRAM;
	unsigned char *buffer_save = NULL;
	char dump_name[64];
	int game_size=0;
	unsigned long save_size=0;
	FILE *myfile;
	const char * wheel[] = { "-","\\","|","/"}; //erase wheel
	unsigned char manufacturer_id=0;
	unsigned char chip_id=0;
	unsigned short flash_id=0;
	unsigned short sector_number=0;

  // Rom Header info

	unsigned char ROM_Logo[48];
    unsigned char Game_Name[16];
	unsigned char Rom_Type=0;
    unsigned long Rom_Size=0;
	unsigned long Ram_Size=0;
	unsigned char CGB=0;
	unsigned char SGB=0;

const unsigned char GB_Logo[48] = {
	0xCE, 0xED, 0x66, 0x66, 0xCC, 0x0D, 0x00, 0x0B, 0x03, 0x73, 0x00, 0x83, 0x00, 0x0C, 0x00, 0x0D, 
	0x00, 0x08, 0x11, 0x1F, 0x88, 0x89, 0x00, 0x0E, 0xDC, 0xCC, 0x6E, 0xE6, 0xDD, 0xDD, 0xD9, 0x99, 
	0xBB, 0xBB, 0x67, 0x63, 0x6E, 0x0E, 0xEC, 0xCC, 0xDD, 0xDC, 0x99, 0x9F, 0xBB, 0xB9, 0x33, 0x3E, 
};
   

   // Main Program   

    printf("\n");
    printf(" ---------------------------------\n");
    printf("    GB Dumper USB2 Software     \n");
    printf(" ---------------------------------\n");
	printf("\n");

    printf("Init LibUSB... \n");

  /* Initialise libusb. */

  res = libusb_init(0);
  if (res != 0)
  {
    fprintf(stderr, "Error initialising libusb.\n");
    return 1;
  }

    printf("LibUSB Init Sucessfully ! \n");


 printf("Detecting GameBoy Dumper... \n");

  /* Get the first device with the matching Vendor ID and Product ID. If
   * intending to allow multiple demo boards to be connected at once, you
   * will need to use libusb_get_device_list() instead. Refer to the libusb
   * documentation for details. */

  handle = libusb_open_device_with_vid_pid(0, 0x1209, 0xBEBA);

  if (!handle)
  {
    fprintf(stderr, "Unable to open device.\n");
    return 1;
  }

  /* Claim interface #0. */

 res = libusb_claim_interface(handle, 0);
  if (res != 0)
  {
	res = libusb_claim_interface(handle, 1);
	 if (res != 0)
  {
    printf("Error claiming interface.\n");
    return 1;}
  }

// Clean Buffer
  for (i = 0; i < 64; i++)
    {
      usb_buffer_in[i]=0x00;
      usb_buffer_out[i]=0x00;
	}


 printf("GameBoy Dumper Found ! \n");
 printf("Reading cartridge...\n");


 // At this step we can try to read the buffer wake up GB Dumper

  usb_buffer_out[0] = WAKEUP;// Affect request to  WakeUP Command

  libusb_bulk_transfer(handle, 0x01,usb_buffer_out, sizeof(usb_buffer_out), &numBytes, 0); // Send Packets to Sega Dumper
  
libusb_bulk_transfer(handle, 0x82, usb_buffer_in, sizeof(usb_buffer_in), &numBytes, 0); // Receive packets from Sega Dumper

		
    printf("\nGB Dumper %.*s",6, (char *)usb_buffer_in);
	printf("\n");
    printf("Hardware Firmware version : %d", usb_buffer_in[20]);
    printf(".%d\n", usb_buffer_in[21]);
    printf("Software Firmware version : %d",MAX_VERSION);
    printf(".%d\n",MIN_VERSION);


  for (i = 0; i < 64; i++)
    {
      usb_buffer_in[i]=0x00;
      usb_buffer_out[i]=0x00;
	}

// Now try to detect cartridge type : GB or GBA or Empty

printf("\nTry to read cartridge type ...\n");

address=260;
game_size=260+64;
usb_buffer_out[0] = READ_GB;
usb_buffer_out[1] = address & 0xFF ;
usb_buffer_out[2] = (address & 0xFF00)>>8;
usb_buffer_out[3]=(address & 0xFF0000)>>16;
usb_buffer_out[5]=game_size & 0xFF;
usb_buffer_out[6]=(game_size & 0xFF00)>>8;
usb_buffer_out[7]=(game_size & 0xFF0000)>>16;
usb_buffer_out[4] = 0; // Slow Mode
libusb_bulk_transfer(handle, 0x01,usb_buffer_out, sizeof(usb_buffer_out), &numBytes, 60000);
libusb_bulk_transfer(handle, 0x82,usb_buffer_in,64, &numBytes, 60000);

for (i = 0; i < 48; i++)
    {
        ROM_Logo [i] = usb_buffer_in[i];
		
    }

if(memcmp((unsigned char *)ROM_Logo,(unsigned char *)GB_Logo,48) == 0)
	{
		printf("Nintendo GameBoy cartridge detected !");
	}
else {printf("Bad header , cartridge dirty or empty Flash ROM");}


/*
printf("\nDisplaying USB IN buffer\n\n");

   for (i = 0; i < 64; i++)
    {
        printf("%02X ",usb_buffer_in[i]);
		j++;
		if (j==16){printf("\n");j=0;}
    }
*/

// Now try to read ROM GB Header


address=308;
game_size=308+64;
usb_buffer_out[0] = READ_GB;
usb_buffer_out[1] = address & 0xFF ;
usb_buffer_out[2] = (address & 0xFF00)>>8;
usb_buffer_out[3]=(address & 0xFF0000)>>16;
usb_buffer_out[5]=game_size & 0xFF;
usb_buffer_out[6]=(game_size & 0xFF00)>>8;
usb_buffer_out[7]=(game_size & 0xFF0000)>>16;
usb_buffer_out[4] = 0; // Slow Mode
libusb_bulk_transfer(handle, 0x01,usb_buffer_out, sizeof(usb_buffer_out), &numBytes, 60000);
libusb_bulk_transfer(handle, 0x82,usb_buffer_in,64, &numBytes, 60000);

/*
printf("\nDisplaying USB IN buffer\n\n");

   for (i = 0; i < 64; i++)
    {
        printf("%02X ",usb_buffer_in[i]);
		j++;
		if (j==16){printf("\n");j=0;}
    }
*/
printf("\nReading ROM Header...\n");
printf("\nGame Title : ");
for (i=0; i<16; i++) {Game_Name[i]=usb_buffer_in[i];} // ROM Name
printf("%.*s",16,(char *) Game_Name);
Rom_Type = usb_buffer_in[19];
printf("\nCartridge Type : %02X ",Rom_Type);
if ( Rom_Type == 0x00){ printf("(ROM ONLY)");}
if ( Rom_Type == 0x01){ printf("(MBC1)");}
if ( Rom_Type == 0x02){ printf("(MBC1+RAM)");}
if ( Rom_Type == 0x03){ printf("(MBC1+RAM+BATTERY)");}
if ( Rom_Type == 0x05){ printf("(MBC2)");}
if ( Rom_Type == 0x06){ printf("(MBC2+BATTERY)");}
if ( Rom_Type == 0x08){ printf("(ROM+RAM)");}
if ( Rom_Type == 0x09){ printf("(ROM+RAM+BATTERY)");}
if ( Rom_Type == 0x0B){ printf("(MMM01)");}
if ( Rom_Type == 0x0C){ printf("(MMM01+RAM)");}
if ( Rom_Type == 0x0D){ printf("(MMM01+RAM+BATTERY)");}
if ( Rom_Type == 0x0F){ printf("(MBC3+TIMER+BATTERY)");}
if ( Rom_Type == 0x10){ printf("(MBC3+TIMER+RAM+BATTERY)");}
if ( Rom_Type == 0x11){ printf("(MBC3)");}
if ( Rom_Type == 0x12){ printf("(MBC3+RAM)");}
if ( Rom_Type == 0x13){ printf("(MBC3+RAM+BATTERY)");}
if ( Rom_Type == 0x19){ printf("(MBC5)");}
if ( Rom_Type == 0x1A){ printf("(MBC5+RAM)");}
if ( Rom_Type == 0x1B){ printf("(MBC5+RAM+BATTERY)");}
if ( Rom_Type == 0x1C){ printf("(MBC5+RUMBLE)");}
if ( Rom_Type == 0x1D){ printf("(MBC5+RUMBLE+RAM)");}
if ( Rom_Type == 0x1E){ printf("(MBC5+RUMBLE+RAM+BATTERY)");}
if ( Rom_Type == 0x20){ printf("(MBC6)");}
if ( Rom_Type == 0x22){ printf("(MBC7+SENSOR+RUMBLE+RAM+BATTERY)");}
if ( Rom_Type == 0xFC){ printf("(POCKET CAMERA)");}
if ( Rom_Type == 0xFD){ printf("(BANDAI TAMA5)");}
if ( Rom_Type == 0xFE){ printf("(HuC3)");}
if ( Rom_Type == 0xFF){ printf("(HuC1+RAM+BATTERY)");}
Rom_Size= (32768 << usb_buffer_in[20]); // Rom Size
printf("\nGame Size is :  %ld Ko",Rom_Size/1024);
if ( Rom_Type != 0x06) {
Ram_Size = usb_buffer_in[21];
printf("\nRam Size : ");
if ( Ram_Size == 0x00){ printf("None");}
if ( Ram_Size == 0x01){ printf("2 Ko");save_size=2*1024;}
if ( Ram_Size == 0x02){ printf("8 Ko");save_size=8*1024;}
if ( Ram_Size == 0x03){ printf("32 Ko ");save_size=32*1024;}
if ( Ram_Size == 0x04){ printf("128 Ko");save_size=128*1024;}
if ( Ram_Size == 0x05){ printf("64 Ko");save_size=64*1024;}
}
else{Ram_Size = 512; printf("\nRam Size : 512 bytes ");save_size=512;}
CGB = usb_buffer_in[15];
if ( CGB  == 0xC0){ printf("\nGame only works on GameBoy Color");}
else { printf("\nGameBoy / GameBoy Color compatible game");}
SGB = usb_buffer_in[18];
if ( SGB  == 0x00){ printf("\nNo Super GameBoy enhancements");}
if ( SGB  == 0x03){ printf("\nGame have Super GameBoy enhancements");}

// MBC5 custom inits


// Clean Buffer
  for (i = 0; i < 64; i++)
    {
      usb_buffer_in[i]=0x00;
      usb_buffer_out[i]=0x00;
	}
/*
if (Rom_Type == 0x19 || 0x1A || 0x1B || 0x1C || 0x1D || 0x1E)
{printf("\nMBC5 detected please wait until init is completed ...\n");
address=0;
game_size = Rom_Size;
usb_buffer_out[0] = READ_GB;           				
usb_buffer_out[1]=address & 0xFF;
usb_buffer_out[2]=(address & 0xFF00)>>8;
usb_buffer_out[3]=(address & 0xFF0000)>>16;
usb_buffer_out[4]=0;
usb_buffer_out[5]=game_size & 0xFF;
usb_buffer_out[6]=(game_size & 0xFF00)>>8;
usb_buffer_out[7]=(game_size & 0xFF0000)>>16;
usb_buffer_out[8]=Rom_Type;
BufferTemp = (unsigned char*)malloc(game_size); 
     for (i=0; i<game_size; i++)
        {
            BufferTemp[i]=0x00;
        }			


						libusb_bulk_transfer(handle, 0x01,usb_buffer_out, sizeof(usb_buffer_out), &numBytes, 60000);
						res = libusb_bulk_transfer(handle, 0x82,BufferTemp,game_size*2 , &numBytes, 60000);
  							if (res != 0)
  								{
    								printf("Error \n");
    								return 1;
  								}     
 						printf("MBC5 init completed sucessfully !\n");}
*/

// Clean Buffer
  for (i = 0; i < 64; i++)
    {
      usb_buffer_in[i]=0x00;
      usb_buffer_out[i]=0x00;
	}
	
printf("\n\n --- MENU ---\n");
printf(" 1) Dump GB ROM\n");
printf(" 2) Dump GB Save\n"); 
printf(" 3) Write GB Save\n"); 
printf(" 4) Erase GB Save\n"); 
printf(" 5) Write GB Flash\n");
printf(" 6) Erase GB Flash\n");
printf(" 7) Flash Sector Erase\n");
printf(" 8) Flash Memory Detection \n");
printf(" 0) Debug\n"); 


printf("\nYour choice: \n");
scanf("%d", &choixMenu);

switch(choixMenu)
{

case 1: // READ GB ROM
 
    	choixMenu=0;
				printf(" 1) Auto (from header)\n");
        		printf(" 2) Manual\n");
				printf(" Your choice: ");
        		scanf("%d", &choixMenu);
					if(choixMenu!=1)
					{
            			printf(" Enter number of KB to dump: ");
            			scanf("%d", &game_size);
						game_size *= 1024;
					}
					else {game_size = Rom_Size; }
				if (Rom_Type == 0x19 || 0x1A || 0x1B || 0x1C || 0x1D || 0x1E){game_size=game_size*2;}		    
				printf("Sending command Dump ROM \n");
        		printf("Dumping please wait ...\n");
				address=0;
				if (Rom_Type == 0x19 || 0x1A || 0x1B || 0x1C || 0x1D || 0x1E){printf("\nRom Size : %ld Ko \n",game_size/1024/2);}
				else{printf("\nRom Size : %ld Ko \n",game_size/1024);}
        // Cleaning Buffer
   
// Cleaning ROM Buffer
address=0;
BufferROM = (unsigned char*)malloc(game_size); 
     for (i=0; i<game_size; i++)
        {
            BufferROM[i]=0x00;
        }			

						usb_buffer_out[0] = READ_GB;           				
						usb_buffer_out[1]=address & 0xFF;
            			usb_buffer_out[2]=(address & 0xFF00)>>8;
            			usb_buffer_out[3]=(address & 0xFF0000)>>16;
            			usb_buffer_out[4]=0;
						usb_buffer_out[5]=game_size & 0xFF;
            			usb_buffer_out[6]=(game_size & 0xFF00)>>8;
            			usb_buffer_out[7]=(game_size & 0xFF0000)>>16;
						usb_buffer_out[8]=Rom_Type;

/*
						usb_buffer_out[6]=usb_buffer_in[20]; // for calculate number of rom bank
						usb_buffer_out[7]=usb_buffer_in[21]; // for calculate number of ram bank*/

						libusb_bulk_transfer(handle, 0x01,usb_buffer_out, sizeof(usb_buffer_out), &numBytes, 60000);
						printf("ROM dump in progress...\n"); 
						res = libusb_bulk_transfer(handle, 0x82,BufferROM,game_size, &numBytes, 60000);
  							if (res != 0)
  								{
    								printf("Error \n");
    								return 1;
  								}     
 						printf("\nDump ROM completed !\n");
						if ( CGB  == 0xC0){myfile = fopen("dump_gbc.gbc","wb");}
         				else {myfile = fopen("dump_gb.gb","wb");}
						if (Rom_Type == 0x19 || 0x1A || 0x1B || 0x1C || 0x1D || 0x1E){fwrite(BufferROM+game_size/2,1,game_size/2, myfile);}
						else {fwrite(BufferROM, 1,game_size, myfile);}
       					fclose(myfile);
 break;


case 2: // READ GB SAVE
 
    			choixMenu=0;
				printf(" 1) Auto (from header)\n");
        		printf(" 2) Manual\n");
				printf(" Your choice: ");
        		scanf("%d", &choixMenu);
					if(choixMenu!=1)
					{
            			printf(" Enter number of byte to dump: ");
            			scanf("%d", &save_size );
						Ram_Size *= 1024;
					}
						    
				printf("Sending command Dump SAVE \n");
        		printf("Dumping please wait ...\n");
				address=0;
				printf("\nSave Size : %ld Ko \n",save_size/1024);
				BufferRAM = (unsigned char*)malloc(save_size);
   
// Cleaning RAM Buffer
     for (i=0; i<save_size; i++)
        {
            BufferRAM[i]=0x00;
        }
	
		address=0;

						usb_buffer_out[0] = READ_GB_SAVE;           				
						usb_buffer_out[1]=address & 0xFF;
            			usb_buffer_out[2]=(address & 0xFF00)>>8;
            			usb_buffer_out[3]=(address & 0xFF0000)>>16;
            			usb_buffer_out[4]=0;
						usb_buffer_out[8]=Rom_Type;
						usb_buffer_out[9]=save_size/1024;


libusb_bulk_transfer(handle, 0x01,usb_buffer_out, sizeof(usb_buffer_out), &numBytes, 60000);
						printf("RAM dump in progress...\n"); 
						res = libusb_bulk_transfer(handle, 0x82,BufferRAM,save_size, &numBytes, 60000);
  							if (res != 0)
  								{
    								printf("Error \n");
    								return 1;
  								}     
 						printf("\nDump Save completed !\n");
						//myfile = fopen("dump_gb.sav","wb");
						if ( CGB  == 0xC0){myfile = fopen("dump_gbc.sav","wb");}
         				else {myfile = fopen("dump_gb.sav","wb");}
						fwrite(BufferRAM, 1,save_size, myfile);
       					fclose(myfile);
						break;

 case 3:  // WRITE SRAM

        printf(" Save file: ");
        scanf("%60s", dump_name);
        myfile = fopen(dump_name,"rb");
        fseek(myfile,0,SEEK_END);
        save_size = ftell(myfile);
        buffer_save = (unsigned char*)malloc(save_size);
        rewind(myfile);
        fread(buffer_save, 1, save_size, myfile);
        fclose(myfile);

        // Write SRAM

        i=0;
        j=0;
		k=0;
        address=0;
        while ( j < save_size)
        {
            // Fill usb out buffer with save data
            for (i=32; i<64; i++)
            {
                usb_buffer_out[i] = buffer_save[k];
                k++;
            }
            i=0;
            j+=32;
            usb_buffer_out[0] = WRITE_GB_SAVE; // Select write in 8bit Mode
            usb_buffer_out[1]=address & 0xFF;
            usb_buffer_out[2]=(address & 0xFF00)>>8;
            usb_buffer_out[3]=(address & 0xFF0000)>>16;
            usb_buffer_out[7] = 0x00;
            libusb_bulk_transfer(handle, 0x01,usb_buffer_out, sizeof(usb_buffer_out), &numBytes, 60000);
            while ( usb_buffer_in[7] != 0xAA)
            {
                libusb_bulk_transfer(handle, 0x82, usb_buffer_in, sizeof(usb_buffer_in), &numBytes, 6000);
            }
            address+=32;
        }

        printf("SRAM Sucessfully Writted ...\n");
        break;



case 4: // Erase GB SAVE
 
    			choixMenu=0;
				printf("Erasing GB Save...");
				buffer_save = (unsigned char*)malloc(1024*32);
				i=0;
				// Cleaning buffer save
            	for (i=0; i<1024*32; i++)
            		{
                		buffer_save[i] = 0xFF;         
            		}
				 i=0;
        j=0;
		k=0;
        address=0;
        while ( j < 1024*32)
        {
            // Fill usb out buffer with save data
            for (i=32; i<64; i++)
            {
                usb_buffer_out[i] = buffer_save[k];
                k++;
            }
            i=0;
            j+=32;
            usb_buffer_out[0] = WRITE_GB_SAVE; // Select write in 8bit Mode
            usb_buffer_out[1]=address & 0xFF;
            usb_buffer_out[2]=(address & 0xFF00)>>8;
            usb_buffer_out[3]=(address & 0xFF0000)>>16;
            usb_buffer_out[7] = 0x00;
            libusb_bulk_transfer(handle, 0x01,usb_buffer_out, sizeof(usb_buffer_out), &numBytes, 60000);
            while ( usb_buffer_in[7] != 0xAA)
            {
                libusb_bulk_transfer(handle, 0x82, usb_buffer_in, sizeof(usb_buffer_in), &numBytes, 6000);
            }
            address+=32;
        }
        	    
        printf("\nSRAM Sucessfully Erased ...\n");

				break;

 case 5: //WRITE FLASH

		// Sending ROM to Buffer

		printf(" Enter ROM file: ");
        scanf("%60s", dump_name);
        myfile = fopen(dump_name,"rb");
        fseek(myfile,0,SEEK_END);
        game_size = ftell(myfile);
        BufferROM = (unsigned char*)malloc(game_size);
        rewind(myfile);
        fread(BufferROM, 1, game_size, myfile);
        fclose(myfile);

        i=0;
        address = 0;
    	j=0;
		k=0;

		printf("Writing Flash please wait ...\n");
   
 		// Fill usb out buffer with ROM data

    while ( j < game_size)
        {
          
            for (i=32; i<64; i++)
            {
                usb_buffer_out[i] = BufferROM[k];
                k++;
            }
            i=0;
            j+=32;

            usb_buffer_out[0] = WRITE_GB_FLASH; // Select write in 8bit Mode
            usb_buffer_out[1]=address & 0xFF;
            usb_buffer_out[2]=(address & 0xFF00)>>8;
            usb_buffer_out[3]=(address & 0xFF0000)>>16;
            usb_buffer_out[7] = 0x00;
			usb_buffer_out[8]=0x1A;
            libusb_bulk_transfer(handle, 0x01,usb_buffer_out, sizeof(usb_buffer_out), &numBytes, 60000);
            while ( usb_buffer_in[7] != 0xAA)
            {
                libusb_bulk_transfer(handle, 0x82, usb_buffer_in, sizeof(usb_buffer_in), &numBytes, 6000);
            }
            address+=32;
        }

        printf("Flash Sucessfully Writted ...\n");
		break;

 case 6: //ERASE FLASH

        usb_buffer_out[0] = ERASE_GB_FLASH;
        libusb_bulk_transfer(handle, 0x01,usb_buffer_out, sizeof(usb_buffer_out), &numBytes, 60000);
        i=0;
        while(usb_buffer_in[0]!=0x01)
        {
            libusb_bulk_transfer(handle, 0x82, usb_buffer_in, sizeof(usb_buffer_in), &numBytes, 6000);   //wait status
            printf("\r ERASE flash in progress: %s ", wheel[i]);
            fflush(stdout);
            i++;
            if(i==4)
            {
                i=0;
            }
        }

        printf("\r ERASE SMD flash in progress: 100%%");
        fflush(stdout);

        break;

case 7: //ERASE Sector Test

		printf(" Enter sector number to erase : \n ");
        scanf("%d", &sector_number);
		usb_buffer_out[0] = ERASE_SECTOR;
		usb_buffer_out[1] = sector_number;
		libusb_bulk_transfer(handle, 0x01,usb_buffer_out, sizeof(usb_buffer_out), &numBytes, 60000);
		libusb_bulk_transfer(handle, 0x82, usb_buffer_in, sizeof(usb_buffer_in), &numBytes, 6000); 
		while ( usb_buffer_in[7] != 0xAA)
            {
                libusb_bulk_transfer(handle, 0x82, usb_buffer_in, sizeof(usb_buffer_in), &numBytes, 6000);
            }
		printf("Sector Erased sucesfully \n");
		break;		
	    

case 8: // Vendor / ID Info


						//printf("Detecting Flash...\n");
						printf("Try to Detect AMD compatible Flash...\n");
						usb_buffer_out[0] = INFOS_ID;
						usb_buffer_out[1] = 0x01;  // AMD Manufacturer ID
						libusb_bulk_transfer(handle, 0x01,usb_buffer_out, sizeof(usb_buffer_out), &numBytes, 60000);
						libusb_bulk_transfer(handle, 0x82, usb_buffer_in, sizeof(usb_buffer_in), &numBytes, 6000); 
						manufacturer_id = usb_buffer_in[1];
						chip_id = usb_buffer_in[3];
						printf("Manufacturer ID : %02X    ",usb_buffer_in[1]);
						printf("Chip ID : %02X \n",usb_buffer_in[3]);
						flash_id = (manufacturer_id<<8) | chip_id;
						//printf("Flash ID : %04X \n",flash_id);
						switch(flash_id)
						  {
								case 0x01AD :   printf("Memory : AM29F016 \n");printf("Capacity : 16Mb \n");break;
								case 0x0141 :   printf("Memory : AM29F032 \n");printf("Capacity : 32Mb \n");break;
								default : 		printf("No AMD or compatible Flash detected \n");			break;
                          }
						scanf("%d");
								
						break; 



case 0:  // DEBUG

        while (1)
        {
            printf("\n\nEnter ROM Address ( decimal value) :\n \n");
            scanf("%ld",&address);
			usb_buffer_out[0] = READ_GB;
			usb_buffer_out[1] = address & 0xFF ;
			usb_buffer_out[2] = (address & 0xFF00)>>8;
			usb_buffer_out[3]=(address & 0xFF0000)>>16;
			usb_buffer_out[4] = 0; // Slow Mode

           libusb_bulk_transfer(handle, 0x01,usb_buffer_out, sizeof(usb_buffer_out), &numBytes, 60000);
libusb_bulk_transfer(handle, 0x82,usb_buffer_in,64, &numBytes, 60000);


printf("\nDisplaying USB IN buffer\n\n");

   for (i = 0; i < 64; i++)
    {
        printf("%02X ",usb_buffer_in[i]);
		j++;
		if (j==16){printf("\n");j=0;}
    }
        }
  

}

		
return 0;

}

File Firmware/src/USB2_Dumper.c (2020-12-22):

/*
USB2 GameBoy Dumper
X-death 12/2020
*/

#include <string.h>
#include <stdlib.h>

// include only used LibopenCM3 lib

#include <libopencm3/stm32/rcc.h>
#include <libopencm3/stm32/gpio.h>
#include <libopencm3/usb/usbd.h>

// Define Dumper Pinout

#define D0 GPIO9  // PB8   GB Data lines
#define D1 GPIO8  // PB9
#define D2 GPIO10 // PB10
#define D3 GPIO11 // PB11
#define D4 GPIO12 // PB12
#define D5 GPIO13 // PB13
#define D6 GPIO14 // PB14
#define D7 GPIO15 // PB15

#define OE GPIO9  //PA9    GB Control lines
#define WE GPIO10 //PA10
#define CE GPIO8  //PA8
#define RESET GPIO6  // PA6
#define A15 GPIO5          // PA5
#define AUDIO_IN	GPIO7  // PA7  GB Extra lines

#define CPU_CLK 	GPIO7  // PB7

#define CLK_CLEAR 	GPIO0  // PA0  Dumper MUX
#define CLK1 		GPIO3  // PA3
#define CLK2 		GPIO4  // PA4

#define LED_PIN 	GPIO13 // PC13  STM32 Led
#define CLEAR_ALL_PINS	0x44444444
#define AS_INPUT    0x44444444
#define AS_OUTPUT    0x33333333

// USB Special Command

#define WAKEUP     		0x10
#define READ_GB         0x11
#define READ_GB_SAVE  	0x12
#define WRITE_GB_SAVE 	0x13
#define ERASE_GB_SAVE	0x17
#define WRITE_GB_FLASH 	0x14
#define ERASE_GB_FLASH 	0x15
#define INFOS_ID 		0x18
#define ERASE_SECTOR    0x16
#define DEBUG_MODE 		0x19

// Version 

#define MAX_VERSION 	1
#define MIN_VERSION 	2

// USB Specific VAR

static char serial_no[25];
static uint8_t usb_buffer_IN[64];
static uint8_t usb_buffer_OUT[64];

// GB Dumper Specific Var

static const unsigned char stmReady[] = {'R','E','A','D','Y','!'};
static unsigned char dump_running = 0;
static unsigned long address = 0;
static unsigned long offset = 0;
static unsigned char Bank = 0; // Number of ROM bank always start at bank 1
static unsigned char Mapper = 0;   // Mapper Type
static unsigned char Ram_Size = 0;   // Mapper Type
static unsigned char Init_Mapper = 0;   // Mapper Type
static unsigned char Init_Flash = 0;   // Mapper Type

//  USB Specific Fonction /////

static const struct usb_device_descriptor dev =
{
    .bLength = USB_DT_DEVICE_SIZE,
    .bDescriptorType = USB_DT_DEVICE,
    .bcdUSB = 0x0200,
    .bDeviceClass = 0xff,
    .bDeviceSubClass = 0,
    .bDeviceProtocol = 0,
    .bMaxPacketSize0 = 64,
    .idVendor = 0x1209,
    .idProduct = 0xBEBA,
    .bcdDevice = 0x0200,
    .iManufacturer = 1,
    .iProduct = 2,
    .iSerialNumber = 3,
    .bNumConfigurations = 1,
};

static const struct usb_endpoint_descriptor data_endp[] = {{
        .bLength = USB_DT_ENDPOINT_SIZE,
        .bDescriptorType = USB_DT_ENDPOINT,
        .bEndpointAddress = 0x01,
        .bmAttributes = USB_ENDPOINT_ATTR_BULK,
        .wMaxPacketSize = 64,
        .bInterval = 1,
    }, {
        .bLength = USB_DT_ENDPOINT_SIZE,
        .bDescriptorType = USB_DT_ENDPOINT,
        .bEndpointAddress = 0x82,
        .bmAttributes = USB_ENDPOINT_ATTR_BULK,
        .wMaxPacketSize = 64,
        .bInterval = 1,
    }
};

static const struct usb_interface_descriptor data_iface[] = {{
        .bLength = USB_DT_INTERFACE_SIZE,
        .bDescriptorType = USB_DT_INTERFACE,
        .bInterfaceNumber = 1,
        .bAlternateSetting = 0,
        .bNumEndpoints = 2,
        .bInterfaceClass = 0xff,
        .bInterfaceSubClass = 0,
        .bInterfaceProtocol = 0,
        .iInterface = 0,

        .endpoint = data_endp,
    }
};

static const struct usb_interface ifaces[] = {{
        .num_altsetting = 1,
        .altsetting = data_iface,
    }
};

static const struct usb_config_descriptor config =
{
    .bLength = USB_DT_CONFIGURATION_SIZE,
    .bDescriptorType = USB_DT_CONFIGURATION,
    .wTotalLength = 0,
    .bNumInterfaces = 1,
    .bConfigurationValue = 1,
    .iConfiguration = 0,
    .bmAttributes = 0x80,
    .bMaxPower = 0x32,

    .interface = ifaces,
};

static void usb_setup(void)
{
    /* Enable clocks for USB */
    //rcc_usb_prescale_1();
    rcc_periph_clock_enable(RCC_USB);

    // Cleaning USB Buffer

    int i=0;

    for(i = 0; i < 64; i++)
    {
        usb_buffer_IN[i]=0x00;
        usb_buffer_OUT[i]=0x00;
    }
}

static const char *usb_strings[] =
{
    "Ultimate-Consoles",
    "USB2 Yes Another GB reader",
    serial_no,
};

static char *get_dev_unique_id(char *s)
{
    volatile uint8_t *unique_id = (volatile uint8_t *)0x1FFFF7E8;
    int i;

    // Fetch serial number from chip's unique ID
    for(i = 0; i < 24; i+=2)
    {
        s[i] = ((*unique_id >> 4) & 0xF) + '0';
        s[i+1] = (*unique_id++ & 0xF) + '0';
    }
    for(i = 0; i < 24; i++)
        if(s[i] > '9')
            s[i] += 'A' - '9' - 1;

    return s;
}

//  GB Dumper Specific Fonction /////

void wait(long nb)
{
    while(nb)
    {
        __asm__("nop");
        nb--;
    }
}

void setDataInput()
{
    GPIO_CRH(GPIOB) = 0x44444444; //set pb8-15 as data IN;
//gpio_set_mode(GPIOB, GPIO_MODE_OUTPUT_50_MHZ,GPIO_CNF_OUTPUT_PUSHPULL,D0|D1|D2|D3|D4|D5|D6|D7);

}

void setDataOutput()
{
    GPIO_CRH(GPIOB) = 0x33333333;
    //gpio_set_mode(GPIOB, GPIO_MODE_OUTPUT_50_MHZ,GPIO_CNF_OUTPUT_PUSHPULL,D0|D1|D2|D3|D4|D5|D6|D7);
}

void setAddress (unsigned long address)
{

    GPIO_CRH(GPIOB) = 0x33333333; //set pb8-15 as data OUT

    GPIO_ODR(GPIOB) = ((address) & 0xFF) << 8;
    GPIOA_BRR |= CLK1;
    GPIOA_BSRR |= CLK1;

    GPIO_ODR(GPIOB) = (address) & 0xFF00; //address MSB
    GPIOA_BRR |= CLK2;
    GPIOA_BSRR |= CLK2;

    GPIO_CRH(GPIOB) = 0x44444444; //set pb8-15 as data IN

}


void writeGB(int address, int byte)
{
    setAddress(address);
    setDataOutput();
	GPIO_ODR(GPIOB) = (byte<<8);
    GPIOA_BRR |= WE;
    wait(256);
    GPIOA_BSRR |= WE;
   // GPIOA_BRR |= AUDIO_IN;
    setDataInput();
}

void writeFlash8(int address, int byte)
{
 	setAddress(address);
    setDataOutput();
	GPIO_ODR(GPIOB) = (byte<<8);
	GPIO_BRR(GPIOA) |= (CE | WE);
	wait(32);
	GPIO_BSRR(GPIOA) |= (CE | WE);
    setDataInput();
}



unsigned long address_mapper;
unsigned long address_max;
unsigned char prev_Bank;

void currentROMBank()
{
    if(address < 0x4000)
    {
        Bank = 0;
    }
    else
    {
        Bank = (address/0x4000); //page num max 0xFF - 32mbits
    }
}

void currentRAMBank()
{
    if(address < 0xBFFF)
    {
        Bank = 0;
    }
    else
    {
        Bank = (address/0xBFFF); //page num max 0xFF - 32mbits
    }
}
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

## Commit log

2020-10-10 Add PCB Folder
    [GB Dumper.sch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]
2020-10-18 Change bootloader to HID STM32
2020-12-22 Preliminary Flash support and fix issue with MBC3 based cartridge
    [USB2_Dumper.c]
